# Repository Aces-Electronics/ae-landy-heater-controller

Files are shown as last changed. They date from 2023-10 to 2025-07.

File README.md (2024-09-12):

<h1 align="center">
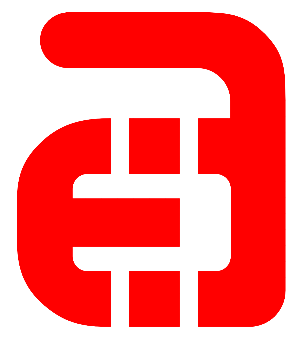
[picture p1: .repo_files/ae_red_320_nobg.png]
Ace's Electronics
    

  Ace's Electronics Pty Ltd  
  12V heater controller for mirrors and windscreens  
</h1>

# Looking to get up and running?
- [Wiki - Quickstart Guide](../../wiki/Quickstart-Guide)

# Project Goals:
The overall goal of this project is to make a simple, robust and reliable heater controller for vehicles that have heated mirrors and windscreens, like a Land Rover Defender for example. The controller will be solid state and be able to handle up to 30A at 12-14V with a maximum input voltage of 20V.

# Design goals:  
- Smallest form-factor possible while being able to handle 30A without getting too hot
- Simple configuration
- Easy to mount
- Zero maintenance

# JonoTron-3000 v0.3
Version 0.3 was made to address a small issue with the switch pull-up, which was incorrectly tied to 12V instead of 3.3V. The hardware pull-up has been removed completely in ths version as the ESP32 has internal pull-ups that are more than capable.

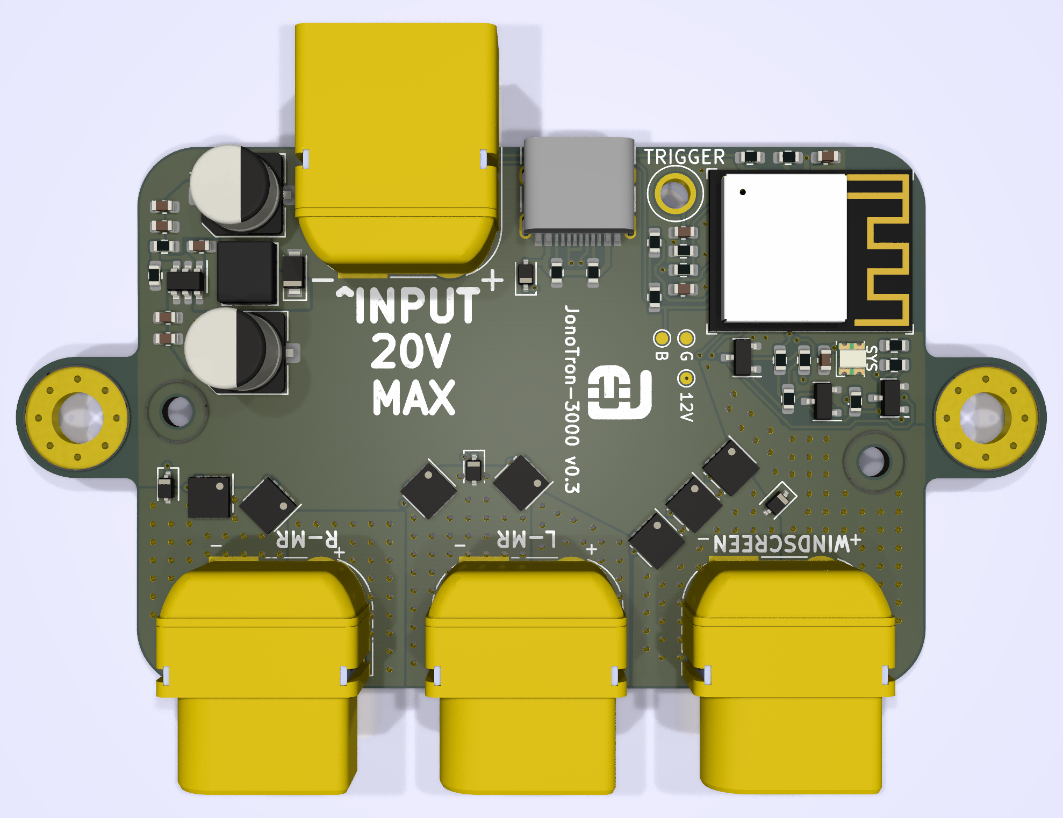
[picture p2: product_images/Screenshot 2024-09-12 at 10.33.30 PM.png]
v0.3 Front

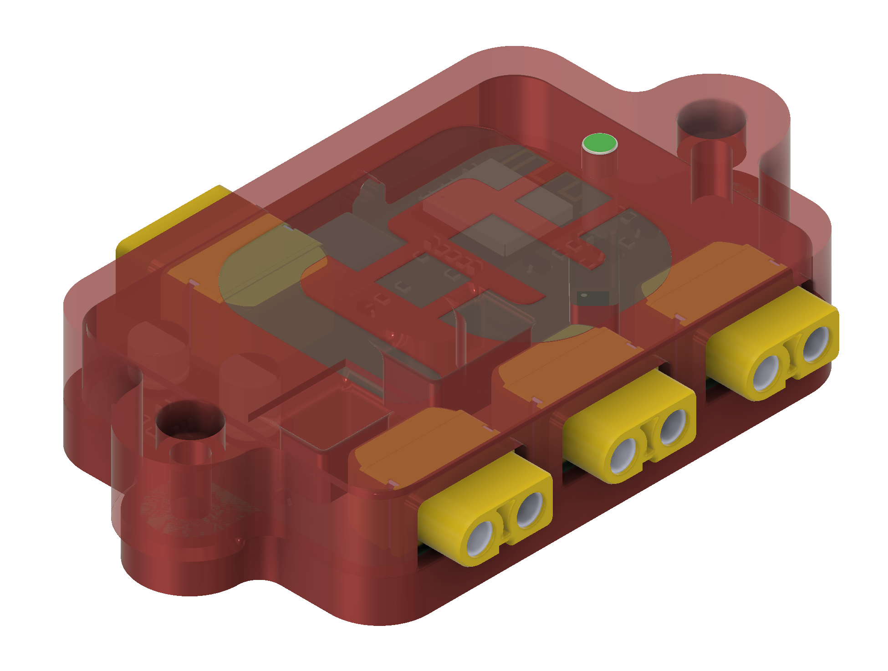
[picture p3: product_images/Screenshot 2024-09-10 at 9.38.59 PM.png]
AE-Land-Heater_Controller

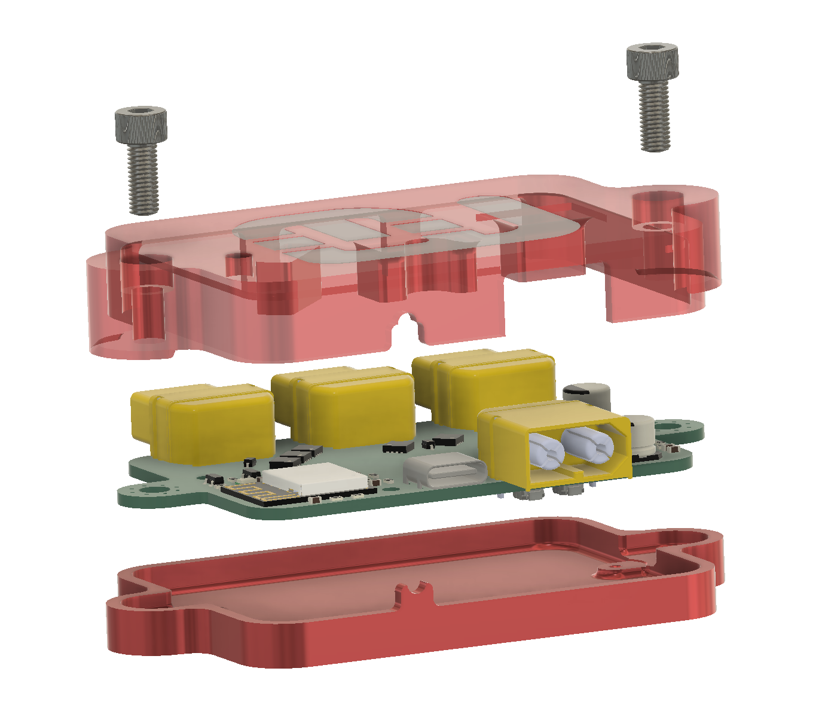
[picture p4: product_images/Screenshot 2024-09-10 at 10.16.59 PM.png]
AE-Land-Heater_Controller-Exploded


# JonoTron-3000 v0.2
Version 0.2 was made to addresss a couple of isssues, namely:
- Input and ouputs polarity was swapped, thanks to the xt-60 injection mould anomally that made a - look like a + when I eyeballed it to see which side was negative
- All outputs were tied together and were't individually controllable
- The board couldn't really handle 30A, not safely

Boards are tested and workng well!

v0.2 renders: 

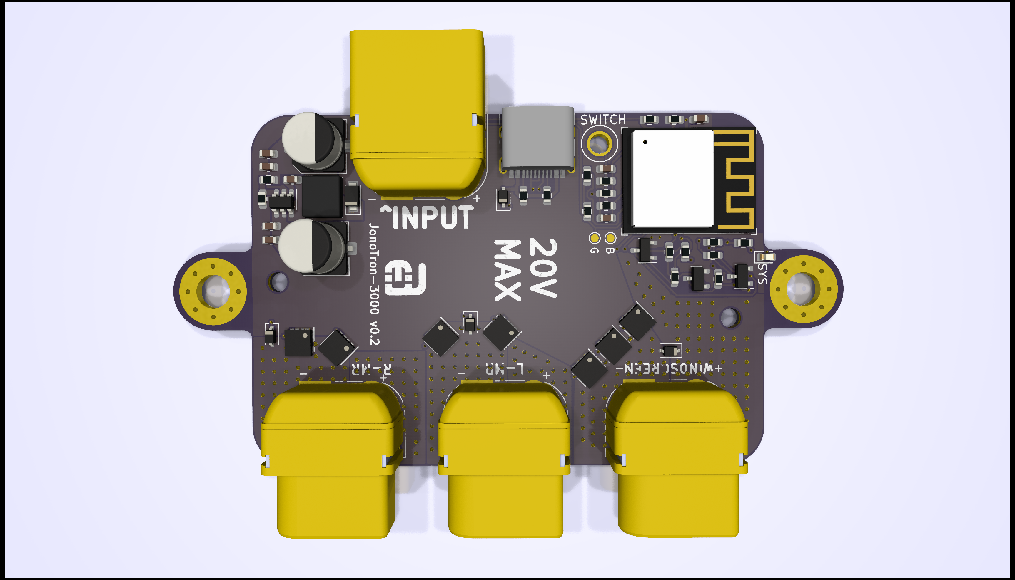
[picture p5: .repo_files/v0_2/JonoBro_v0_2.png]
v0.2 Front


# Where to Buy:
Available to purchase in Australia or New Zealand via <a href="https://d1b959-f7.myshopify.com/">The AE Store</a>

## Support:
Contact me direct via ace<@>aceselectronics.com.au, just make it look like a normal email address. (hiding from the bots ;)

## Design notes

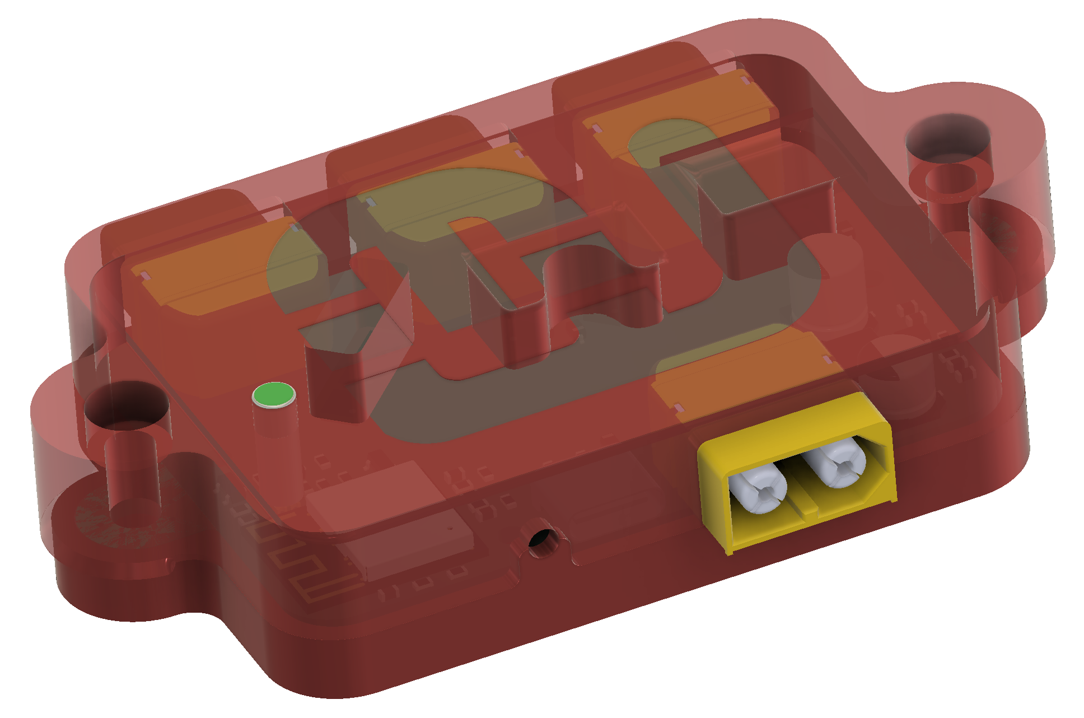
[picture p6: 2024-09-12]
product_images/Screenshot 2024-09-10 at 9.39.46 PM.png

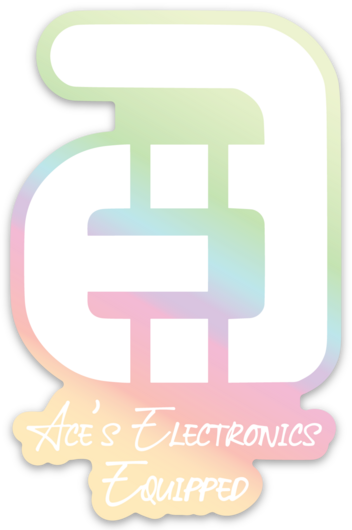
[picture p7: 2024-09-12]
branding/ae_equipped.png

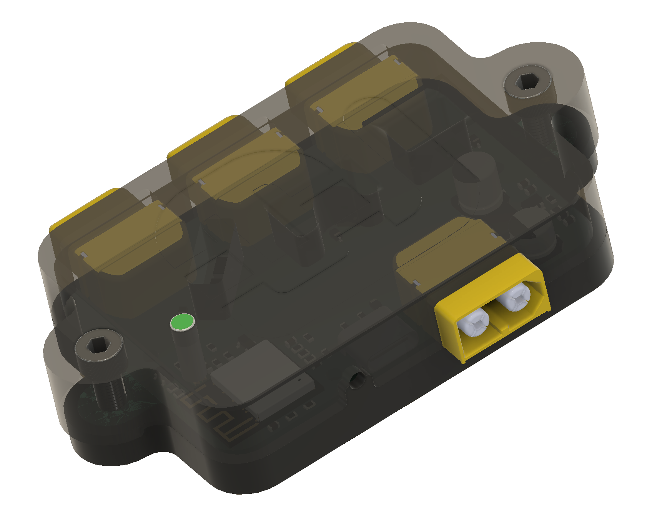
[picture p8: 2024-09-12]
product_images/Screenshot 2024-09-11 at 2.56.26 PM.png

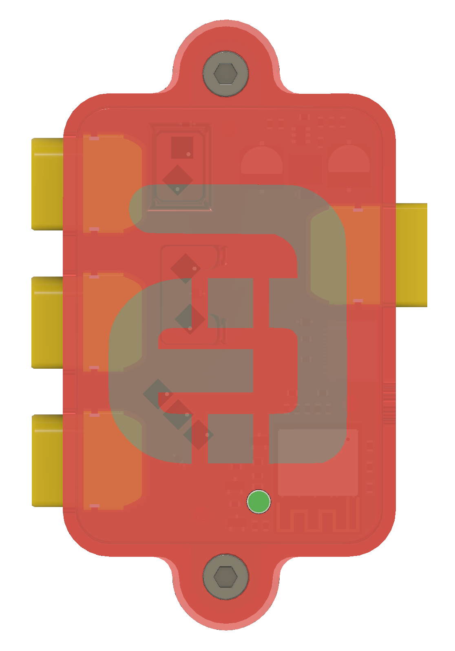
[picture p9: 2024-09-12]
product_images/Screenshot 2024-09-10 at 10.55.12 PM.png

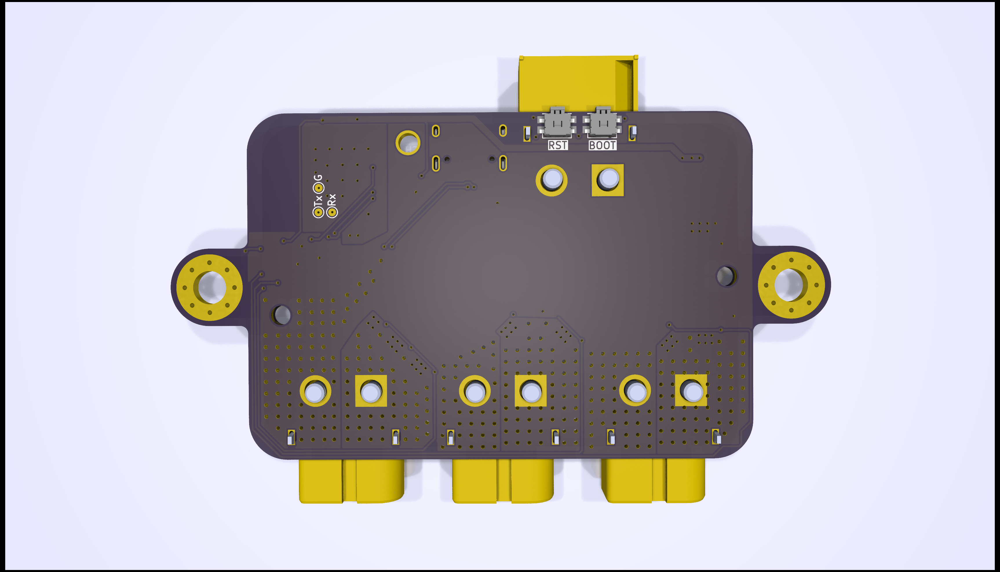
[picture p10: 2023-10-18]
.repo_files/v0_2/JonoBro_rear_v0_2.png

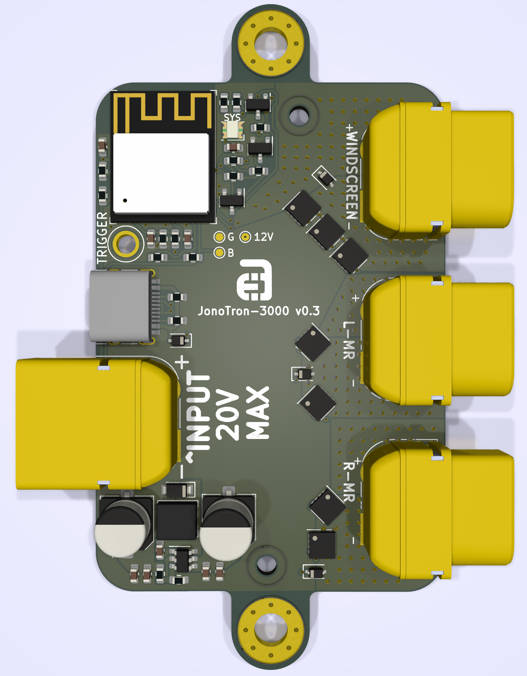
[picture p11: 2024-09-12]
product_images/Screenshot 2024-09-12 at 10.32.08 PM.png

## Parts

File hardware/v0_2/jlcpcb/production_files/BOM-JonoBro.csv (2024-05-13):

Comment | Designator | Footprint | LCSC
SW_Push | SW1,SW2 | ALPSALPINE-SKSCLBE010_C115361 | C115361
100nF | C11 | C_0603_1608Metric | C1525
USB_C_Receptacle_USB2.0 | J6 | USB_C_Receptacle_HRO_TYPE-C-31-M-12 | C165948
1k | R15,R17,R8 | R_0603_1608Metric | C21190
13k | R1,R10,R11,R12,R16,R18,R19,R5,R7,R9 | R_0603_1608Metric | C22797
4.3k | R2 | R_0603_1608Metric | C23159
5.1k | R13,R14 | R_0603_1608Metric | C23186
10uH | L1 | L_Chilisin_BMRA00040415 | C2847473
1N5819WS | D4,D5,D6,D7 | D_SOD-323 | C2927280
100nF | C10,C2,C3,C4,C6,C7,C8,C9 | C_0603_1608Metric | C30926
CSD19537Q3 | Q1,Q10,Q3,Q5,Q6,Q8,Q9 | VSON-8_3.3x3.3mm_P0.65mm_NexFET | C315567
220uF | C1 | CP_Elec_6.3x7.7 | C340768
2.2k | R4 | R_0603_1608Metric | C4190
Conn_01x02_Pin | J1,J2,J3 | AMASS_XT60PW-F_1x02_P7.20mm_Horizontal | C428722
AOZ1280CI | U1 | SOT-23-6 | C5123971
ESP32-C3-MINI-1 | U2 | ESP32-C3-MINI-1 | C5290152
MMBT3904 | Q2,Q4,Q7 | SOT-23 | C8512
WS2812-2020 | D2 | LED_WS2812B-2020_PLCC4_2.0x2.0mm | C965555
PMEG6020ER | D1 | Nexperia_CFP3_SOD-123W | C98663
Conn_01x02_Pin | J4 | AMASS_XT60PW-M_1x02_P7.20mm_Horizontal | C98732
22uF | C5 | CP_Elec_6.3x5.4 | C98744

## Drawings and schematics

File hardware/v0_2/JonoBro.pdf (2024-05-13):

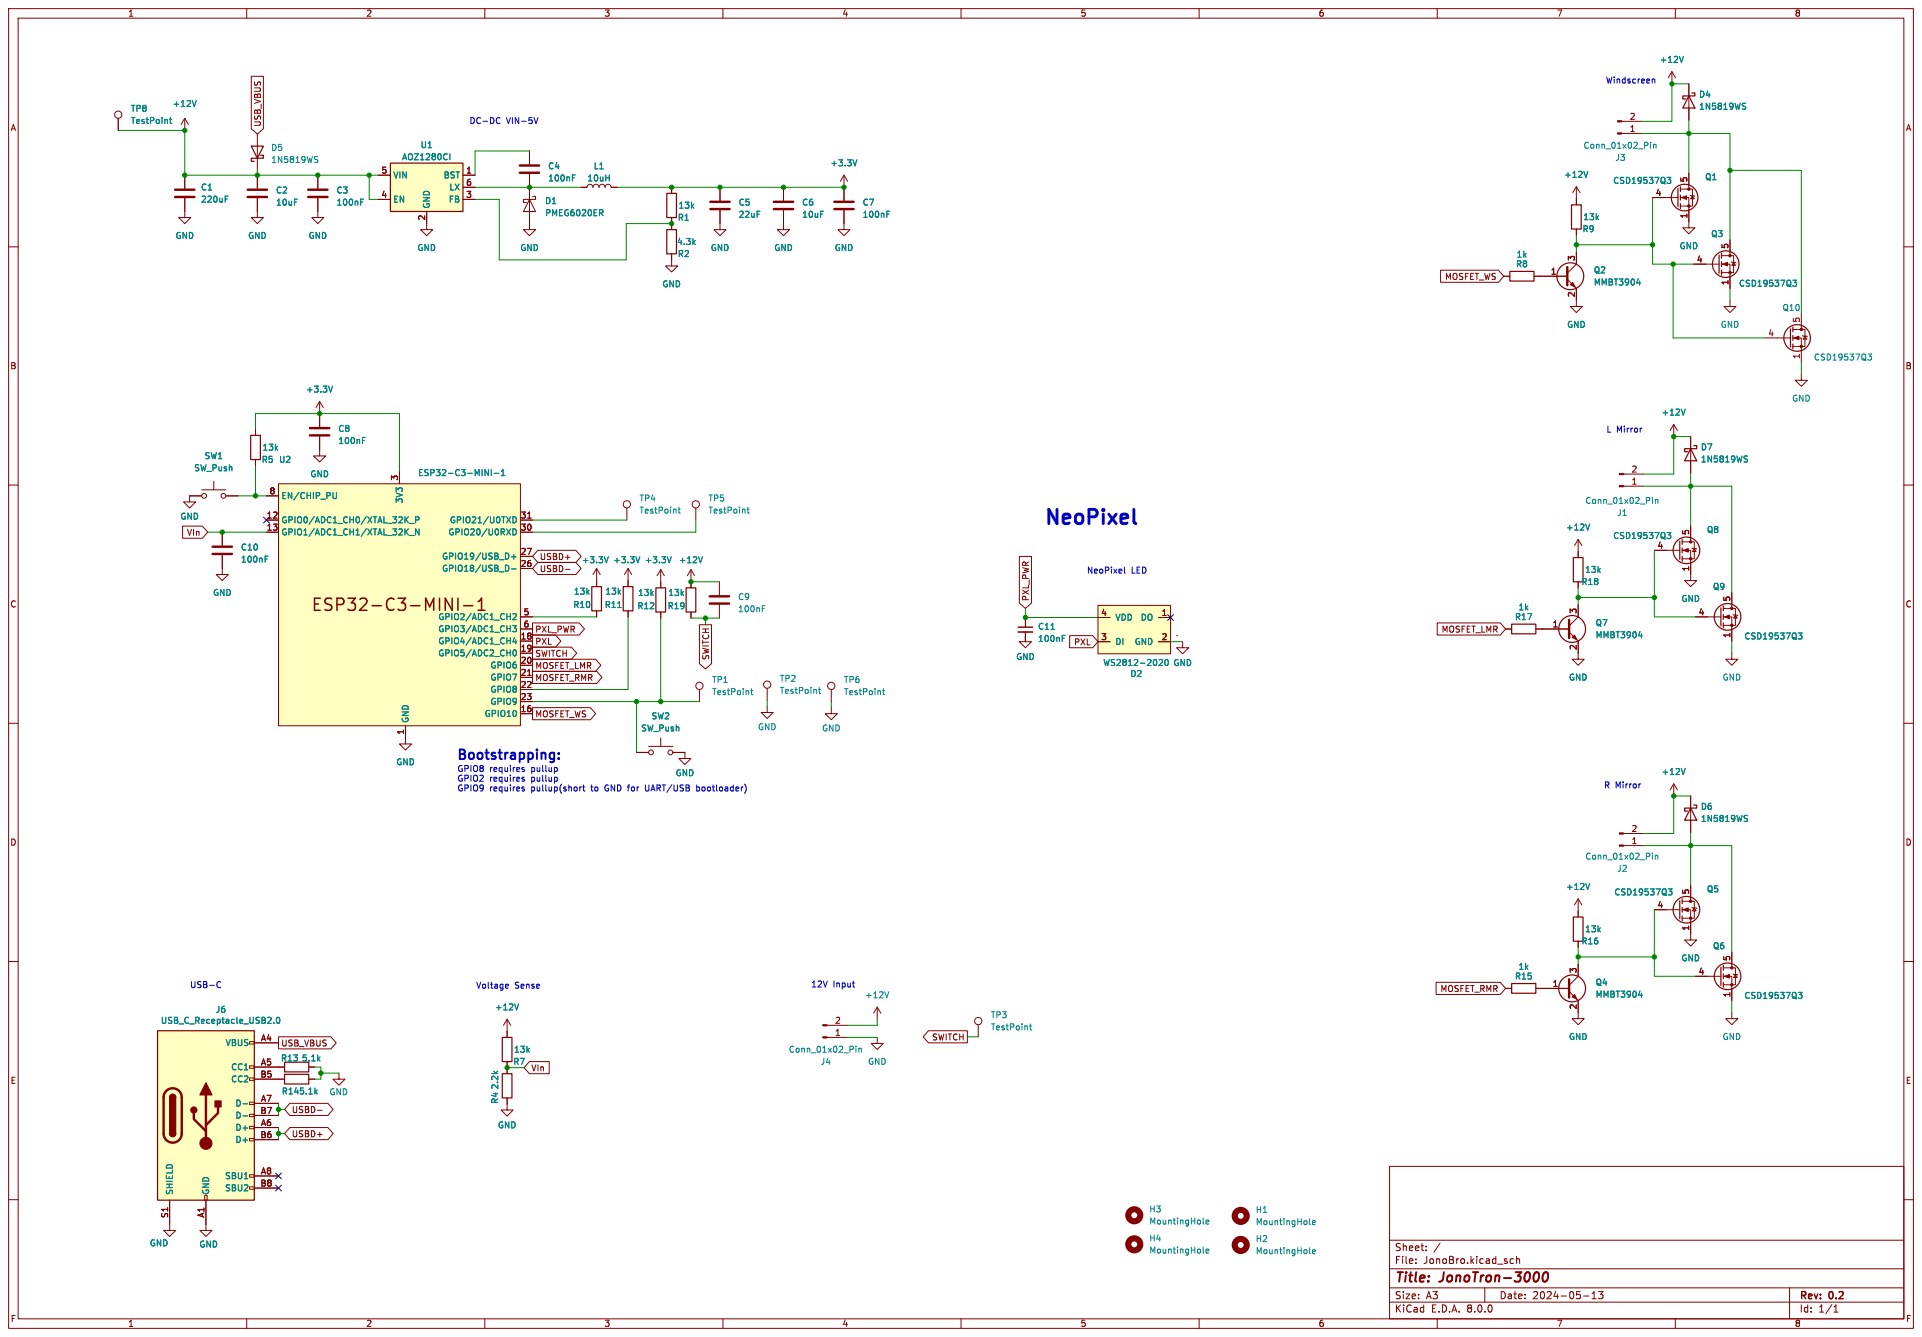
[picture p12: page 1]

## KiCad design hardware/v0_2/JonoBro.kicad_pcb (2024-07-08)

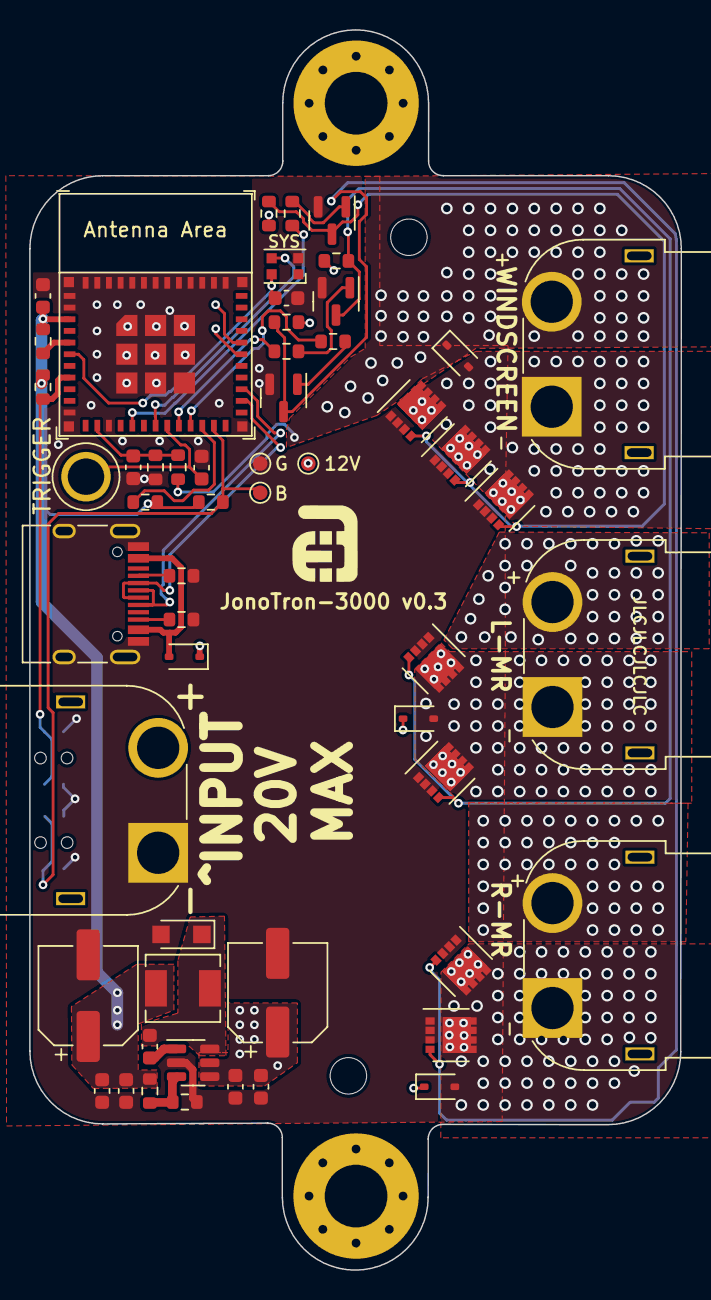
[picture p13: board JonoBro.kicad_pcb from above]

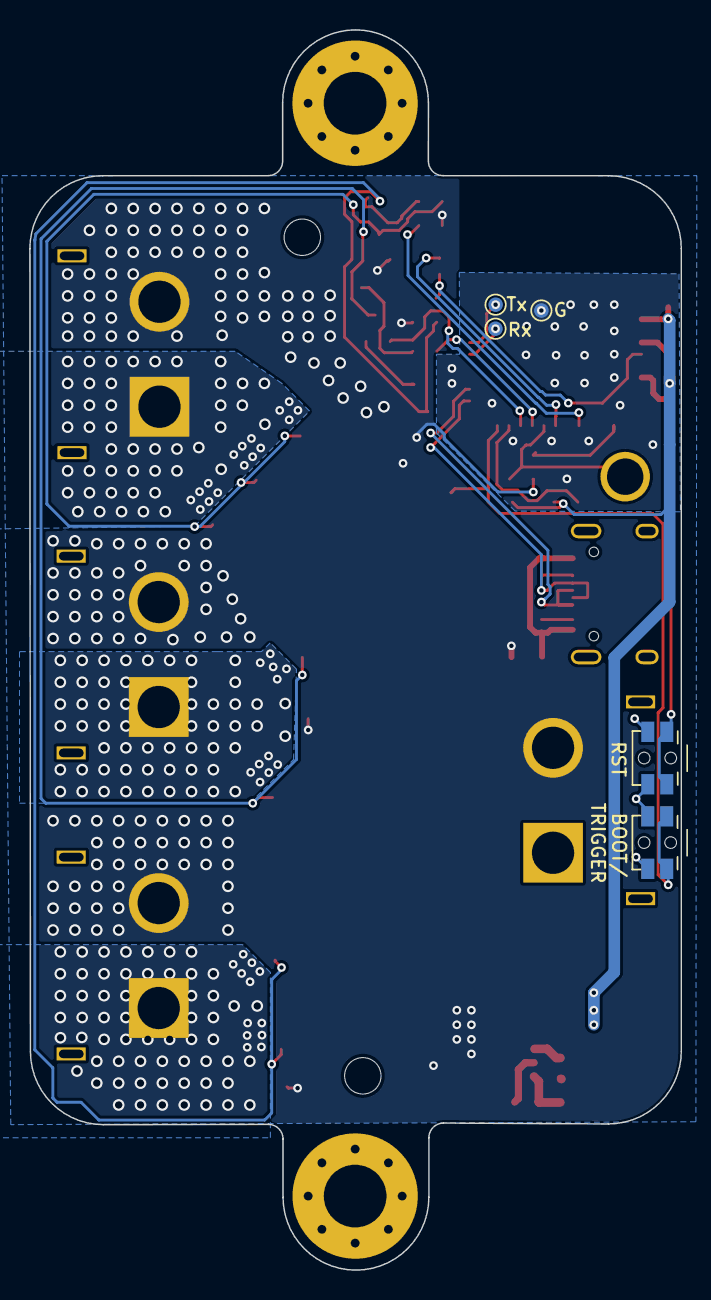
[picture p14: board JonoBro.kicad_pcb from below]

Board: 2 copper layers, 44.7 x 85.1 mm, 64 parts (5 on the bottom side), 33 nets.

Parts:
C1: 220uF; CP_Elec_6.3x7.7
C2, C6: 10uF; C_0603_1608Metric
C3, C4, C7, C8, C9, C10, C11: 100nF; C_0603_1608Metric
C5: 22uF; CP_Elec_6.3x5.4
D1: PMEG6020ER; Nexperia_CFP3_SOD-123W
D2: WS2812-2020; LED_WS2812B-2020_PLCC4_2.0x2.0mm
D4, D5, D6, D7: 1N5819WS; D_SOD-323
H1, H2: MountingHole; MountingHole_2.5mm
H3, H4: MountingHole; MountingHole_4.3mm_M4_Pad_Via
J1, J2, J3: Conn_01x02_Pin; AMASS_XT60PW-F_1x02_P7.20mm_Horizontal
J4: Conn_01x02_Pin; AMASS_XT60PW-M_1x02_P7.20mm_Horizontal
J6: USB_C_Receptacle_USB2.0; USB_C_Receptacle_HRO_TYPE-C-31-M-12
L1: 10uH; L_Chilisin_BMRA00040415
Q1, Q3, Q5, Q6, Q8, Q9, Q10: CSD19537Q3; VSON-8_3.3x3.3mm_P0.65mm_NexFET
Q2, Q4, Q7: MMBT3904; SOT-23
R1, R5, R7, R9, R10, R11, R12, R16, R18: 13k; R_0603_1608Metric
R2: 4.3k; R_0603_1608Metric
R4: 2.2k; R_0603_1608Metric
R8, R15, R17: 1k; R_0603_1608Metric
R13, R14: 5.1k; R_0603_1608Metric
SW1, SW2: SW_Push; ALPSALPINE-SKSCLBE010_C115361
TP1, TP2, TP4, TP5, TP6, TP8: TestPoint; TestPoint_Pad_D1.0mm
TP3: TestPoint; TestPoint_Loop_D3.80mm_Drill2.5mm
U1: AOZ1280CI; SOT-23-6
U2: ESP32-C3-MINI-1

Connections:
+3.3V: C5.1, C6.1, C7.1, C8.1, L1.2, R1.1, R5.1, R10.1, R11.1, R12.1, U2.3 (3V3)
+12V: C1.1, C2.1, C3.1, D4.1 (K), D5.1 (K), D6.1 (K), D7.1 (K), J1.2, J2.2, J3.2, J4.2, R7.1, R9.1, R16.1, R18.1, TP8.1, U1.4 (EN), U1.5 (VIN)
GND: C1.2, C2.2, C3.2, C5.2, C6.2, C7.2, C8.2, C9.2, C10.2, C11.2, D1.2 (A), D2.2 (GND), J4.1, J6.A1 (GND), J6.A12 (GND), J6.B1 (GND), J6.B12 (GND), J6.S1 (SHIELD), Q1.1 (S), Q1.2 (S), Q1.3 (S), Q2.2 (E), Q3.1 (S), Q3.2 (S), Q3.3 (S), Q4.2 (E), Q5.1 (S), Q5.2 (S), Q5.3 (S), Q6.1 (S), Q6.2 (S), Q6.3 (S), Q7.2 (E), Q8.1 (S), Q8.2 (S), Q8.3 (S), Q9.1 (S), Q9.2 (S), Q9.3 (S), Q10.1 (S), Q10.2 (S), Q10.3 (S), R2.2, R4.1, R13.1, R14.1, SW1.2, SW2.2, TP2.1, TP6.1, U1.2 (GND), U2.1 (GND), U2.2 (GND), U2.11 (GND), U2.14 (GND), U2.36 (GND), U2.37 (GND), U2.38 (GND), U2.39 (GND), U2.40 (GND), U2.41 (GND), U2.42 (GND), U2.43 (GND), U2.44 (GND), U2.45 (GND), U2.46 (GND), U2.47 (GND), U2.48 (GND), U2.49 (GND), U2.50 (GND), U2.51 (GND), U2.52 (GND), U2.53 (GND)
MOSFET_LMR: R17.1, U2.20 (GPIO6)
MOSFET_RMR: R15.1, U2.21 (GPIO7)
MOSFET_WS: R8.1, U2.16 (GPIO10)
unnamed: C4.2, D1.1 (K), L1.1, U1.6 (LX)
unnamed: D4.2 (A), J3.1, Q1.5 (D), Q3.5 (D), Q10.5 (D)
unnamed: D6.2 (A), J2.1, Q5.5 (D), Q6.5 (D)
unnamed: D7.2 (A), J1.1, Q8.5 (D), Q9.5 (D)
unnamed: J6.A5 (CC1), R13.2
unnamed: J6.B5 (CC2), R14.2
unnamed: Q1.4 (G), Q2.3 (C), Q3.4 (G), Q10.4 (G), R9.2
unnamed: Q2.1 (B), R8.2
unnamed: Q4.1 (B), R15.2
unnamed: Q4.3 (C), Q5.4 (G), Q6.4 (G), R16.2
unnamed: Q7.1 (B), R17.2
unnamed: Q7.3 (C), Q8.4 (G), Q9.4 (G), R18.2
unnamed: C4.1, U1.1 (BST)
unnamed: R1.2, R2.1, U1.3 (FB)
unnamed: R5.2, SW1.1, U2.8 (EN/CHIP_PU)
unnamed: R10.2, U2.5 (GPIO2/ADC1_CH2)
unnamed: R11.2, U2.22 (GPIO8)
unnamed: R12.2, SW2.1, TP1.1, U2.23 (GPIO9)
unnamed: TP5.1, U2.30 (GPIO20/U0RXD)
unnamed: TP4.1, U2.31 (GPIO21/U0TXD)
PXL: D2.3 (DI), U2.18 (GPIO4/ADC1_CH4)
PXL_PWR: C11.1, D2.4 (VDD), U2.6 (GPIO3/ADC1_CH3)
SWITCH: C9.1, TP3.1, U2.19 (GPIO5/ADC2_CH0)
USBD+: J6.A6 (D+), J6.B6 (D+), U2.27 (GPIO19/USB_D+)
USBD-: J6.A7 (D-), J6.B7 (D-), U2.26 (GPIO18/USB_D-)
USB_VBUS: D5.2 (A), J6.A4 (VBUS), J6.A9 (VBUS), J6.B4 (VBUS), J6.B9 (VBUS)
VIn: C10.1, R4.2, R7.2, U2.13 (GPIO1/ADC1_CH1/XTAL_32K_N)

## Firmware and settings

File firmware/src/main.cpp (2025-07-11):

//////
// How to read the LED on the JonoTron Hardware:
//  Flashing red:
//    Battery voltage too low, switch off and auto-mode off, heaters off.
//  Flashing green:
//    Battery voltage okay, switch off and auto-mode off, heaters off.
//  Solid red:
//    Battery voltage too low, switch on or auto-mode on, heaters off.
//  Solid green:
//    Battery voltage okay, switch on or auto-mode on, heaters on.
//  Flash blue once:
//    System booting/rebooting.
//  Flashing blue:
//    If WiFi unconfigured, hardware in setup mode, access the web interface at http://192.168.4.1 after connecting to the ae-update WiFi network.
//    If Wifi configured, accessing Internet and checking for new firmware
//  Solid red/green/blue combined (probably looks mostly white):
//    Software update available, after the system updates the device will restart and the LED will return to the system's state.
/////

//////
// How to use the physical switch:
//  Switch in the on position:
//    Manually turn on the heaters (maybe this should be the enable auto mode function, rather than manual mode on?).
//  Switch in the off position:
//    System in auto mode, will run the heaters every time the car starts for the duration of the timeout set in the web portal (defaults to 10 mins).
//  To turn on the config portal:
//    Turn it on-off three times, pause for a second on each state change (off to on or on to off), toggle the switch on-off-on-off-on-off.
//    You can then connect a phone, laptop or tablet to the ae-update wifi network; no password required. A captive portal with some options should pop up.
//    You can also access the portal, once started, by browsing to http://192.168.4.1
//    The portal will timeout after 3 minutes.
//  To factory default the device:
//    Use the same process as above but toggle the switch on 5 times, then off, so
//    on-off-on-off-on-off-on-off-on-off
//    This will set the auto mode timout to 10 mins and erase all portal/WiFi settings.
//    If you connect the device to your home network, use a factory default to regain access to the portal if you are unable to find the device's IP address, which will  no longer be 192.168.4.1, check the WiFi router's web interface for the
////

#include <Arduino.h>
#include <nvs_flash.h>
#include <Preferences.h>
#include <CircularBuffer.hpp>
#include <WiFiManager.h> // https://github.com/tzapu/WiFiManager
#include <Adafruit_NeoPixel.h>
#include <ESPmDNS.h>
#include <WiFiClientSecure.h>

#define debug_mode true

const char *ssid = "ae-update";  // SSID for WiFi Manager
float onVoltage = 13.80; // input voltage to allow the heaters turn on

#define OTAGH_OWNER_NAME "Aces-Electronics" // github owner for URL concatenation
#define OTAGH_REPO_NAME "ae-landy-heater-controller" // github repo name for URL concatenation

#define OTAGH_OWNER_NAME "Aces-Electronics" // github owner for URL concatenation
#define OTAGH_REPO_NAME "ae-landy-heater-controller" // github repo name for URL concatenation
#include <ota-github-cacerts.h>
#include <ota-github-defaults.h>
#include <OTA-Hub.hpp> // https://github.com/Hard-Stuff/OTA-Hub-diy-example_project

long onTimeTimer = 1;       // default output on time duration (10)
unsigned int timeout = 180; // seconds to run the AP/WiFi client for

unsigned int startTime = millis(); // holds millis() for when the captive portal (WiFi Maneger) was started

const int windscreen = 10;        // WS MOSFET
const int lMirror = 6;            // LMR MOSFET
const int rMirror = 7;            // RMR MOSFET
const int vIn = 1;                // 1
const int sysLEDPWR = 3;          // 3 NeoPixel power
const int sysLED = 4;             // 4 NeoPixel
const int onSwitch = 5;           // 5
const int numReadings = 100;      // ADC samples (of inputVoltage) per poll
long previousMillis = 0;          // stores the previous millis()
long interval = 1000;             // seconds between IO and CLI updates
int dodgySecondsCounter = 0;      // keeps track of how many seconds between switch events
int checkDodgySecondsCounter = 6; // a vlaue it can't ever be, to trigger a timer reset
int neoPixelPin = sysLED;         // casting the sysLED int to the neoPixelPin int
int numPixels = 1;                // number of LEDs

// variables to control brightness levels
int brightness = 100;       // default LED brightness
int brightDirection = -10;  // direction to pulse the LED
long onTime;                // -1 manual/unconfigured
int stateChangeCounter = 0; // counts the on/off toggles for mode setting purposes
int readings[numReadings];  // holder of circular buffer size
int readIndex = 0;          // holder of circular buffer position

char voltageSource[11] = {"unknown"}; // variable to initialise the voltage source

float inputVoltage;       // device input voltage, used to know when not to enable the heater
float lastReading = 13.2; // made up this initial value

bool updateUserCLITimeout = true; // allows the CLI to be updated with the heater timout output
bool enableWiFi = false;          // stores whether or not to enable WiFI AP for the purposes of updating the firmware
bool updateRunning = false;       // stores whether or not the AP has been started
bool check_for_updates = false;   // sets a flag from the timer once per day
bool checkOnFirstConnect = true;  // checks for update on first WiFi connect
bool onSwitchState = 0;           // stores the on switch state, set to 1 (off)
bool eventTimerExpired = 0;       // stores the state of the event timer
bool needToSavePreferences = 0;   // stores whether or not to update preferences, for use in the main loop
bool autoTimeout = 0;             // stores the state of the autoTimeout feature
bool greenBlink = 0;              // green led blink off
bool redBlink = 0;                // red led blink off
bool blueBlink = 0;               // blue led blink off
bool enableOutputs = 0;           // outputs disabled until needed

const float r1 = 13000.0f;                             // R1 in ohm, 13k
const float r2 = 2200.0f;                              // R2 in ohm, 2.2k
float vRefScale = (3.0f / 4096.0f) * ((r1 + r2) / r2); // gives us the voltage per LSB (0.005060369318)

long total = 0;  // holds the number of vakues in the circular buffer
long int t1 = 0; // millis counter 1
long int t2 = 0; // millis counter 2

unsigned long newtime = 0;          // millis counter for startup IO delay
unsigned long lastDebounceTime = 0; // the last time the output pin was toggled
unsigned long debounceDelay = 200;  // the debounce time; increase if the output flickers

Adafruit_NeoPixel strip = Adafruit_NeoPixel(numPixels, neoPixelPin, NEO_GRB + NEO_KHZ800);                           // init lass
WiFiManager wm;                                                                                                      // init class
WiFiManagerParameter custom_heater_timeout("heaterTimeout", "Heater Timeout (0-30 mins, 0=manual enable)", "10", 2); // init class, set the onTime in the portal according to savedparams
WiFiClientSecure wifi_client;                                                                                        // init class

hw_timer_t *check_for_update = NULL;    // init class
hw_timer_t *output_enable_timer = NULL; // init class
hw_timer_t *ap_enable_timer = NULL;     //  init class

Preferences preferences; // init class

CircularBuffer<float, 200> buffer; // init class

// REPLACE WITH THE MAC Address of your receiver
uint8_t broadcastAddress[] = {0xFF, 0xFF, 0xFF, 0xFF, 0xFF, 0xFF}; // ToDo: use this

String success; // variable to store if sending data was successful

void IRAM_ATTR onTimer0() // onTimer0 function, triggers when timer0 expires
{
  check_for_updates = true; // ToDo: make this simpler
  enableWiFi = true;
}

void IRAM_ATTR onTimer1()      // onTimer1 function, triggers when onTimer1 expires
{                              // output timeout
  autoTimeout = true;          // heater timeout has timed out
  updateUserCLITimeout = true; // allow the CLI to be updated with the timeout info
}

void disableAp() // triggers when ap times out
{
  enableWiFi = false;
  updateRunning = false;
  if (wm.getConfigPortalActive())
  {
    wm.stopConfigPortal();
  }
  if (wm.getWebPortalActive())
  {
    wm.stopWebPortal();
  }
}

void switchEvent() // debounce for switch interrupt
{
  if ((millis() - lastDebounceTime) > debounceDelay)
  {
    if (onSwitchState)
    {
      stateChangeCounter++;
    }
  }
  lastDebounceTime = millis();
}

void pulseLED() // pulse LED function
{
  strip.setPixelColor(0, 0, 0, 255); // set pixel to blue
  for (int i = 0; i < 10; i = i + 1)
  {
    brightness = brightness + brightDirection;
    if (brightness < 1)
    {
      brightness = 0;
      brightDirection = -brightDirection;
    }
    else if (brightness > 99)
    {
      brightness = 100;
      brightDirection = -brightDirection;
    }
    delay(5);
    strip.setBrightness(brightness);
    strip.show();
  }
}

long smooth() // fills the circular buffer with voltages
{
  // perform average on sensor readings
  long average;
  // subtract the last reading:
  total = total - readings[readIndex];
  // read the sensor:
  readings[readIndex] = analogRead(vIn);
  // add value to total:
  total = total + readings[readIndex];
  // handle index
  readIndex = readIndex + 1;
  if (readIndex >= numReadings)
  {
    readIndex = 0;
  }
  // calculate the average:
  average = total / numReadings;

  return average;
}

void checkVoltage() // checks the battery voltage
{

  float avg = 0.0;

  buffer.push(smooth() * (vRefScale)); // fill the circular buffer for super smooth values
  using index_t = decltype(buffer)::index_t;
  for (index_t i = 0; i < buffer.size(); i++)
  {
    avg += buffer[i] / buffer.size();
  }
  inputVoltage = avg;

  if (inputVoltage < 13.5)
  {
    strcpy(voltageSource, "battery");
  }
  else
  {
    strcpy(voltageSource, "alternator");
  }
}

void saveParamsCallback() // function to save params from web hook
{
  onTime = atoi(custom_heater_timeout.getValue());
  if (onTime > 30)
  {
    onTime = 30;
  }
  else if (onTime < 0)
  {
    onTime = 0;
  }

  onTime = onTimeTimer;
  needToSavePreferences = true;
  timerAlarmDisable(output_enable_timer);
  timerAlarmWrite(output_enable_timer, onTimeTimer * 60000000, false); // set in portal, 10 by defult
  timerAlarmEnable(output_enable_timer);
}

void factoryReset() // resets everthing to factory settings
{
  nvs_flash_erase(); // erase the NVS partition.
  nvs_flash_init();  // initialize the NVS partition.
  delay(500);
  ESP.restart(); // reset to clear memory
}

void savePreferences() // does the actual preference saving
{
  Serial.println("saving settings to flash");
  preferences.begin("ae-landy-heater", false);
  preferences.putInt("onTime", onTime);
  preferences.end();
  needToSavePreferences = false;
}

void processEventData() // an event has occured, such as a switch has been flipped, proccess the switch state
{
  Serial.printf("Switch has been set high %d times\n", stateChangeCounter);
  Serial.printf("Seconds since switch event (ModeResetCounter) = %i \n\n", t2 - t1);

  if (stateChangeCounter == 1)
  {
    autoTimeout = false; // allows the switch to re-arm
    Serial.println("Switch re-armed!\n");
  }
  else if (stateChangeCounter == 3)
  {
    stateChangeCounter = 0; // reset counter to 0 for the second loop
    enableWiFi = true;      // enable WiFi AP
    Serial.println("AP enabled for configuration!\n");
  }
  else if (stateChangeCounter > 4)
  {
    stateChangeCounter = 0; // reset counter to 0 for the second loop
    Serial.println("Factory reset in 3  2  1!\n");
    wm.resetSettings();
    factoryReset();
  }
  eventTimerExpired = false;
}

void OTACheck() // check for new firmware
{
  // turn everthing off
  digitalWrite(lMirror, HIGH);    // high is off
  digitalWrite(rMirror, HIGH);    // high is off
  digitalWrite(windscreen, HIGH); // high is off

  // Initialise OTA
  wifi_client.setCACert(OTAGH_CA_CERT); // Set the api.github.cm SSL cert on the WiFiSecure modem
  OTA::init(wifi_client);

// Initialise OTA
  wifi_client.setCACert(OTAGH_CA_CERT); // Set the api.github.cm SSL cert on the WiFiSecure modem
  //wifi_client.setInsecure()
  OTA::init(wifi_client);

  // Check OTA for updates
  OTA::UpdateObject details = OTA::isUpdateAvailable();
  details.print();
  if (OTA::NO_UPDATE != details.condition)
  {
      Serial.println("An update is available!");
      // Perform OTA update
      if (OTA::performUpdate(&details) == OTA::SUCCESS)
      {
        // do custom code stuff here
      }
  }
  else
  {
    Serial.println("No new update available. Continuing...");
  }
  check_for_updates = false;
}

void doWiFiManager() // run the WiFi Manager captive portal
{
  if ((millis() - startTime) > (timeout * 1000))
  {
    Serial.println("portaltimeout");
    disableAp();
    check_for_updates = false;
    enableWiFi = false;
  }
  else
  {
    if (check_for_updates)
    {
      if (wm.autoConnect(ssid))
      {
        Serial.println("Updating firmware, switch off heaters...");
        OTACheck(); // only runs if WiFi client is configured and connected
      }
    }
  }
}

void loadPreferences() // load preferences from NVRAM
{
  if (preferences.begin("ae-landy-heater", false))
  {
    if (preferences.getBool("configured"))
    {
      onTime = preferences.getInt("onTime");
      Serial.print("Device has been configured!");
      Serial.printf("Device is running in auto mode and on for %i minutes", onTime);
    }
    else
    {
      preferences.putInt("onTime", 10);
      onTime = preferences.getInt("onTime");
      Serial.printf("Setting onTime to %i minutes", onTime);
      preferences.putBool("configured", true);
    }
    // set WiFiManager value
    char _cstrOnTime[8];
    itoa(onTime, _cstrOnTime, 10);
    custom_heater_timeout.setValue(_cstrOnTime, 2);
  }
  preferences.end();
}

void setup() // run once
{
  // initialise Serial for debugging, uart over USB
  Serial.begin(115200);

  // initialise IO
  pinMode(windscreen, OUTPUT);
  pinMode(lMirror, OUTPUT);
  pinMode(rMirror, OUTPUT);
  pinMode(vIn, INPUT);
  pinMode(sysLEDPWR, OUTPUT);
  digitalWrite(sysLEDPWR, HIGH);
  pinMode(onSwitch, INPUT_PULLUP);

  strip.begin();                     // initialize the strip
  strip.clear();                     // Initialize all pixels to 'off'
  strip.setPixelColor(0, 0, 0, 255); // set pixel to blue
  strip.setBrightness(brightness);
  strip.show();

  // set outputs to off (high = off)
  digitalWrite(windscreen, HIGH);
  digitalWrite(lMirror, HIGH);
  digitalWrite(rMirror, HIGH);

  // load configured settings from NVRAM
  loadPreferences();
  newtime = millis();

  // detect switch events
  attachInterrupt(digitalPinToInterrupt(onSwitch), switchEvent, CHANGE);

  // setup state change counter wipe, to timout enter settings changes/modes
  check_for_update = timerBegin(0, 80, true);
  timerAttachInterrupt(check_for_update, &onTimer0, true);
  //timerAlarmWrite(check_for_update, 86400000000, true); // 24 hours, auto reloads
  timerAlarmWrite(check_for_update, 60000000, true); // 24 hours, auto reloads
  timerAlarmEnable(check_for_update);                   // Enable the timer

  if (onTime > 0) // checks to see if the hardware is configured
  {
    onTimeTimer = onTime;
  }

  output_enable_timer = timerBegin(1, 80, true);
  timerAttachInterrupt(output_enable_timer, &onTimer1, true);
  timerAlarmWrite(output_enable_timer, onTimeTimer * 60000000, true); // set in portal, 30 by defult

  Serial.println("\n\nSetup done");
}
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

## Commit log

2023-09-06 first push
    [JonoBro.kicad_pcb, JonoBro.kicad_sch]
2023-09-07 seems good to me
    [JonoBro.kicad_pcb, JonoBro.kicad_sch]
2023-09-07 changed pcb
    [JonoBro.kicad_pcb]
2023-09-08 v0.1 submitted for PCBA
    [BOM-JonoBro.csv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]
2023-09-08 v0.1 submitted for PCBA take 2
    [JonoBro-CuBottom.gbr, JonoBro-CuTop.gbr, JonoBro-EdgeCuts.gbr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]
2023-10-03 moved things around
    [BOM-JonoBro.csv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]
2023-10-05 pcb updates to 0.2
    [JonoBro.kicad_pcb, JonoBro.kicad_sch]
2023-10-09 WIP, mostly working v0.1
    [JonoBro.kicad_sch]
2023-10-11 0.2 wip
    [JonoBro.kicad_pcb, JonoBro.kicad_sch]
2023-10-11 added switch control, preferences, timeout
2023-10-20 Clean and publish
    [BOM-JonoBro.csv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]
2023-10-22 updated wiring diagram
2024-05-13 v0.2 complete JLCPCB
    [BOM-JonoBro.csv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]
2024-05-27 basic functionality working, no switching yet
2024-07-08 board updates
    [JonoBro.kicad_pcb, JonoBro.kicad_sch]
2024-09-03 added WiFi on LED feedback
2024-09-03 Detect voltage source
2024-09-03 lots of small fixes
    [main.cpp]
2024-09-12 v0.3 updates
    [BOM-JonoBro.csv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]
2025-07-11 testing the timer
